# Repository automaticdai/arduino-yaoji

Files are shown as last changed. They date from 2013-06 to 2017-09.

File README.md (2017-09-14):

# Yaoji - An AR Digital Plant on Arduino and Android
妖姬 - 基于Arduino和Android的虚拟电子植物

----------

## 1. About Yaoji
Yaoji is an open-source digital plant based on Arduino and Android. It is based on the popular idea of Augmented Reality (AR). By using the deployed sensors and Leds on Yaoji, users can interact with Yaoji and see its response on an Android phone.

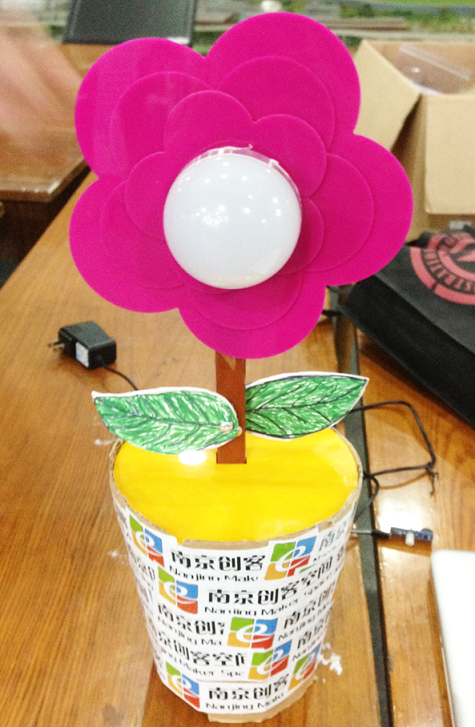
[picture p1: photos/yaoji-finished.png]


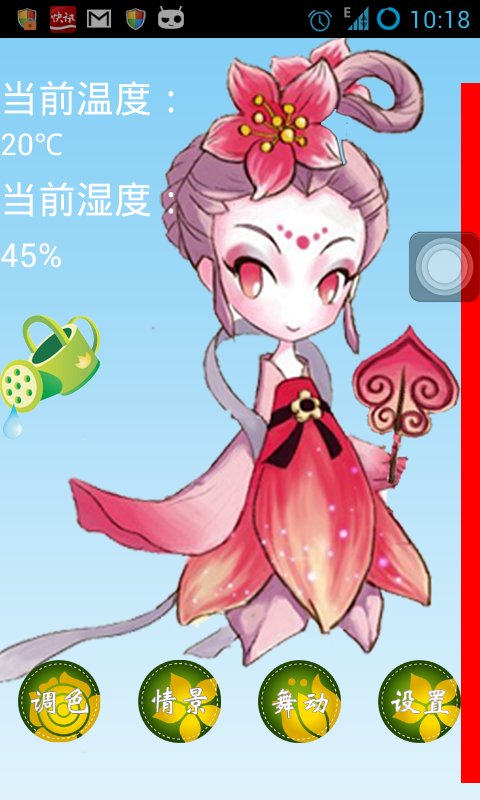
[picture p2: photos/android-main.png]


Yaoji has five full-RGB leds, one illumination sensor, one temperature & humidity sensor and one infrared sensor. Yaoji uses an Arduino Nano 3.0 as the core controller and a wifi module as a bridge to communicate with the Android app. It was a prize-winning (third prize) project in Geekon Hackmarthon in 2013.

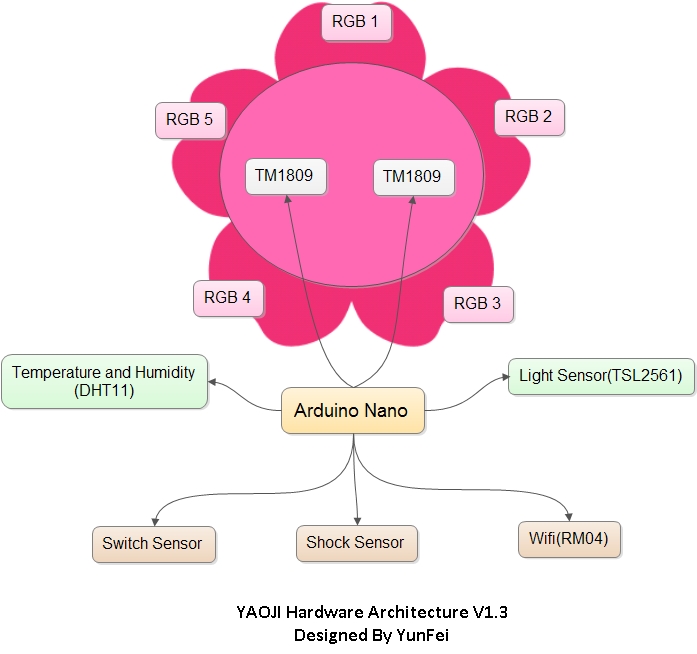
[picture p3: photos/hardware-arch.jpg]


## 2. Project Directory
### /documents
descriptions, datasheets and communication protocol

### /hardware
schematics, pcb and mechanical CAD

### /photos
photos of Yaoji.

### /software
- **/arduino**: Arduino source code and libraries of the firmware (.ino).

- **/android**: user application on Android (.apk).

- **/windowns**: a Windows demo of a sound analyzer that transfer sound spectrum into LED color (Visual Studio Project).

## 3. Contributors
|Name |Role|
|--- |----|
|YunFei  | System Design & Arduino Programming |
|leepood | Android App Development |
|Congbin Zhong | Hardware Design and Debug |

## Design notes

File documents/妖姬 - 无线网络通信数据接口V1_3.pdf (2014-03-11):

妖 姬

# 无线网络通信数据接口

# 南京创客空间

# Nanjing Maker Space

2013 年 6 月

目 录

# 一、通信概述

妖姬使用 Wifi 与客户端进行无线通信，其自身作为无线 AP 热点，使用 UDP 与客户端进行通 信。妖姬默认为空闲模式，进行数据通信前，客户端首先需要建立连接。建立连接后，妖姬 会切换为通信模式，等待客户端发送数据请求。通信期间，客户端需要以固定间隔发送心跳 请求，若超过一定时间没有接收到心跳请求，妖姬会切换回空闲模式，不再响应客户端的请 求。客户端也可主动发送退出连接请求使妖姬切换为空闲模式，空闲模式下妖姬的动作模式 可由客户端配置。

妖姬的通信参数如下：
网络 SSID：yaoji-wifi
网络密钥：yaoji
通信方式：UDP/IP
IP 地址：192.168.1.1
端口号：10001
通信超时：3s，发送数据后若超过该时间没有接收到响应，则需进行重发。 通信重试次数：3 次，通信超时次数若超过该次数，则认为通信失败。 心跳间隔：30s，由客户端定时发送。
空闲超时：60s，在连接状态下，若超过该时间没有接收到心跳，则退出通信模式。

数据类型定义：
数据使用网络字节序大端模式，数据类型如下：
BYTE | 8 位无符号整数，[0-255]
INT16U | 16 位无符号整数，[0-65535]
INT32 | 32 位有符号整形，[-2147483648, +2147483647]
FLOAT | 32 位浮点数类型。
STRING | 字符串类型，需要以’\0’结尾。
BYTE[n] | 长度为 n 的 BYTE 型数组。

# 二、数据帧格式

数据帧符合 UDP/IP 协议，数据定义如下：
开始位(2B) | 数据长度(2B) | 消息类型(2B) | 消息体(nB) | 数据校验(2B) | 结束位(1B)
0x55 0xAA | LENGTH | COMMAND | BODY | BCC | 0x0D

对以上各消息域的说明如下：
LENGTH | 消息总长度 = 消息类型长度 + 消息体长度 + 数据校验长度。每一帧的数 据长度不得超过 1024B。
COMMAND | 消息类型，两字节。
BODY | 消息体：消息类型不同，则长度与内容不同。
BCC | 从”数据长度”至”消息体”之间的所有字节进行累加求和(包括数据长度及消 息体自身)，截取末尾两字节作为校验。

# 三、消息定义

## 3-1 建立连接 CONN

消息类型：0x0001
数据方向：Client -> YAOJI
消息说明：
发送该报文，建立客户端与妖姬的数据连接。
消息定义：
通信协议版本(INT16U 2B) | 保留(INT16U 2B)
V1.12 表示为 0x0112

## 3-2 连接响应 CONN ACK

消息类型：0x8001
数据方向：YAOJI -> Client
消息说明：
对连接请求进行响应。
消息定义：
连接结果(BYTE 1B)
0x00 成功，0x01 已经建立连接，0x02 连接失败(协议版本不一致)

## 3-3 心跳 HRT

消息类型：0x0002
数据方向：Client -> YAOJI
消息说明：
客户端定时发送心跳，维持妖姬的通信状态。若超过空闲时间仍然接收不到心跳，则妖 姬主动断开本次连接。
消息定义：
无消息体。

## 3-4 心跳响应 HRT ACK

消息类型：0x8002
数据方向：YAOJI -> Client
消息说明：

妖姬对心跳进行响应。
消息定义：
心跳结果(BYTE 1B)
0x00 心跳成功，0x01 心跳失败，尚未建立连接

## 3-5 退出连接 DISCON

消息类型：0x0003
数据方向：Client -> YAOJI
消息说明：
客户端主动断开连接。
消息定义：
无消息体。

## 3-6 退出响应 DISCON ACK

消息类型：0x8003
数据方向：YAOJI -> Client
消息说明：
妖姬响应客户端请求，并退出连接。
消息定义：
退出结果(BYTE 1B)
0x00 退出成功，0x01 退出失败，尚未建立连接

## 3-7 读取请求 READ REQUEST

消息类型：0x0004
数据方向：Client -> YAOJI
消息说明：
客户端从妖姬读取参数，包括当前状态、RGB LED 控制值、环境状态等数据。 消息定义：
参数索引(INT16U 2B)
读取参数的索引号，见附录 1。

## 3-8 读取响应 READ ACK

消息类型：0x8004

数据方向：YAOJI-> Client
消息说明：
妖姬响应客户端的读取请求。
消息定义：
参数索引(INT16U 2B) | 参数长度(INT16U 2B) | 参数值(nB)
读取参数的索引号，见附录 1。 | 参数值的字节大小。 0 表示读取失败。 | 参数值域，该长度 n 在参数长 度域给出。该参数的类型解释 是由其参数索引决定的。

## 3-9 写入请求 WRITE REQUEST

消息类型：0x0005
数据方向：Client-> YAOJI
消息说明：
客户端向妖姬写入数据，如修改 LED 的状态、工作模式等。
消息定义：
参数索引(INT16U 2B) | 参数长度(INT16U 2B) | 参数值(nB)
写入参数的索引号，见附录 1。 | 参数值的字节大小。 0 表示读取失败。 | 参数值域，该长度 n 在参数长 度域给出。该参数的类型解释 是由其参数索引决定的。

## 3-10 写入响应 WRITE ACK

消息类型：0x8005
数据方向：YAOJI ->Client
消息说明：
妖姬响应客户端的写入请求。
消息定义：
参数索引(INT16U 2B) | 操作结果(BYTE 1B)
写入参数的索引号，见附录 1。 | 0x00 写入成功 0x01 写入失败(不存在的索引或为只读参数) 0x02 写入失败(超过数据范围)

# 附 1.参数索引表

索引 | 名称 | 类型 | 范围 | R/W | 备注
0x00 | 当前生命 | INT16U | 0-1000 | R/W | [0.1%]当前生命值，浇水可以恢复。
0x01 | 空闲模式 | INT16U | 0-20 | R/W | 设置空闲模式下妖姬的行为模式。
0x02 | 温度 | INT32 | -500-800 | R | [0.1°C]当前环境温度
0x03 | 湿度 | INT32 | 0-1000 | R | [0.1%]环境湿度
0x04 | 气压 | INT32 | 5000-10600 | R | [0.1hPa]当前大气压强度
0x05 | 照度 | INT32 | 0-200000 | R | [1Lux]当前环境光照强度
0x06 | LED1-RGB | BYTE[3] | 0-255 | R/W | LED1 三通道的颜色，顺序为 R-G-B。
0x07 | LED2-RGB | BYTE[3] | 0-255 | R/W | LED2 三通道的颜色，顺序为 R-G-B。
0x08 | LED3-RGB | BYTE[3] | 0-255 | R/W | LED3 三通道的颜色，顺序为 R-G-B。
0x09 | LED4-RGB | BYTE[3] | 0-255 | R/W | LED4 三通道的颜色，顺序为 R-G-B。
0x0A | LED5-RGB | BYTE[3] | 0-255 | R/W | LED5 三通道的颜色，顺序为 R-G-B。
0x0B | LED-ALL | BYTE[3] | 0-255 | W | 同时设置所有的 LED 为该颜色，设 置顺序为 R-G-B。
0x0C | LED-Burst | BYTE[15] | 0-255 | R/W | 批量设置 / 读取所有的 LED 颜色， 设置顺序为： [0-1-2]RGB1 [3-4-5]RGB2 [6-7-8]RGB3 [9-10-11]RGB4 [12-13-14]RGB5
0x0D | SHOCK | BYTE | 0-1 | R/W | 发生震动，写 0 清除。
0x0E | INTERACT_1 | BYTE | 0-1 | R | 交互传感器 1
0x0F | INTERACT_2 | BYTE | 0-1 | R | 交互传感器 2
0x10 | Sensor -Burst | INT16U+ INT32+I NT32+IN T32+BYT E[3] | \ | R | 批量读取 Sensor。顺序：生命、温 度、湿度、光照、震动、交互传感 1、 交互传感 2。
0x11 | Environment | INT8U | 0-2 | R/W | 设置/读取当前的情景模式
0x12
0x13
0x14

空闲模式说明：
0x00 : 空闲模式下关闭所有 LED
0x01 : 保持最后的状态
0x02 : 进入呼吸模式
0x03 : 进入生命模式
0x04 : 进入温度检测模式

0x05 : 进入湿度检测模式

情景模式说明：
0x00：关闭情景模式
0x01：静如流水
0x02：动如脱兔

# 附 2.修订历史

日期 | 版本 | 修订内容 | 修订人
13-06-24 | V1.0 | ·完成通信协议初稿。 | 戴晓天
13-06-25 | V1.1 | ·LED 的颜色以 RGB 为一组同时设置，支持了同时设置所 有 LED 的颜色，提高通信效率。 ·增加了对空闲模式的解释。 | 戴晓天
13-06-29 | V1.2 | ·增加了 16 位无符号整形数据结构 INT16U ·将 ARRAY[n]型数据更名为 BYTE[n] ·将 INT 数据类型更名为 INT32 ·将参数标签和参数长度域修改为 16 位，提高通信效率 ·修改了排版与部分文字说明，增加了目录 ·修改了部分参数的数据类型 | 戴晓天
13-07-07 | V1.3 | ·增加了读取震动传感器、交互传感器，以及传感器批 量读取命令。 ·增加了情景模式设置 | 戴晓天

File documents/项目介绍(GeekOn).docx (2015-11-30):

妖姬项目介绍 - Geekon

● 什么是妖姬

妖姬是互联网时代的宠儿，是一种兼容办公室与居家生活的桌面电子植物。她不仅仅是一展能变换万千色彩的LED灯，她也像真实的植物一样具有情感与生命，她是夜色下妩媚的女神，也是你生活不可缺少的助手。

妖姬基于开源硬件Arduino，五片全彩LED是她的霓裳，可以通过iphone手机控制她的颜色，什么颜色由你定！妖姬使用内置锂电池供电，通过无污染绿色的太阳能进行充电，同时可以用5V USB对她放电，千万别用太高的电压，会电晕她的。

● 和她约会

孤枕难眠：可化作一朵白色雪莲，做你的书童陪你挑灯夜战，做小夜灯帮你吸引蚊子。

激情四射：多种颜色变换，炫舞效果，不同的颜色，按照设定好的节奏闪动。

静如流水：她在夜晚尽展其温柔一面，通过柔和的灯光变换，让你感受从未有过的宁静。

舞动音乐：妖姬随着音乐的旋律，变为月夜下的舞娘。

● 呵护妖姬

妖姬具有独特的生命系统，要像呵护女朋友一样呵护她，您的悉心呵护才能让她茁壮成长，她能通过自身的颜色变化呈现目前的生命状态。开心时心花怒放，不开心时候怒火冲天。当你看到她显示红色的时候，说明她生气了，在发火呢 (赶紧去哄哄她)。如果看上去情况不妙，那就该打开app给她浇水了！

● 妖姬天气

妖姬不止是一个风华绝代的玩物，她还是您的私人气象站。妖姬具有多种环境传感器，只要打开手机APP，就能看见家中温度、湿度、气压、照度情况，真是太赞了！

● 妖姬的由来 (野史)

历世真仙体道通鉴，曾经提起西王母有女儿，有名可查者有六位： 一、四女名为华林，字容真，号紫元夫人，南极元君或称南极王夫人； 二、第十三女名为媚兰，字申林，号右英王夫人，云林夫人或称沧浪云林右英夫人； 三、第二十女名叫清娥，字愈音，或愈意，号紫微王夫人； 四、第二十三女，名为瑶姬，号曰云华夫人； 五、么女，名婉罗或者玉卮，字勃遂，号曰太真王夫人； 六、妖姬，号曰七彩妖姬。

西王母育女多人，有事女儿代其效劳，书中所说王母乃天帝之女，而天帝在道藏记载，分有青、黄、白、黑四天帝，王母到底所指是哪一位天帝，到今日也无 人知晓，西王母仙居在何处，至今也是众人所迷惑，吏书虽有记载但未成定论。

西王母最疼爱的小女儿：妖姬，天资聪颖，天生丽质，古灵精怪，常在天庭里捣乱。妖姬经常跑太上老君和其他众神家去捣蛋，搞破坏。玉皇大帝接受到很多 投诉电话，非常烦恼，想早点把她嫁出去，于是跟王母商量准备把妖姬许配给二郎神。妖姬听说此事后非常生气，想自己的婚姻自己做主。得知民间有非诚勿 扰，随即报名参加了江苏电视台的非诚勿扰。

一枚挨踢吊死男，上了非诚勿扰，看中了天生丽质的妖姬。此时妖姬也被该挨踢男的痴情打动，牵手成功。幸福来的太突然，正当他们还沉浸在幸福中，哪知 那天有不测风云，此时天庭知道妖姬私自下凡人间，派托塔李天王前来捉拿妖姬。妖姬宁死不屈，化作一朵七色彩花。挨踢男伤心欲绝，化作花叶花茎一直陪伴妖姬身边。

虽然目前这个设计还停留在空想阶段，不过我们会发挥极客精神，把想法变成现实。希望大家支持我们，支持南京创客空间，我们“极客行动”见！

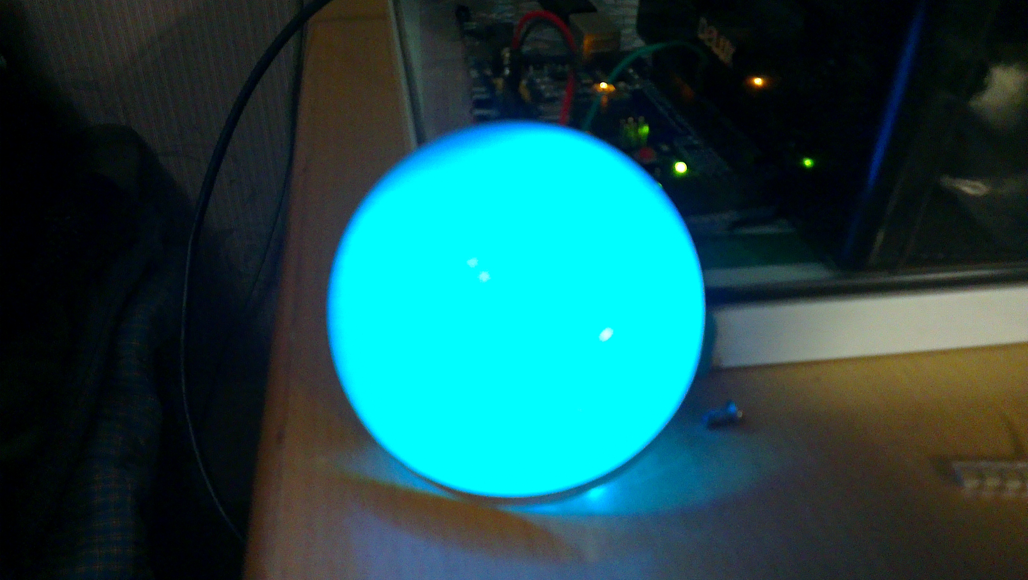
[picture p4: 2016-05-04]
photos/RGB调色3.jpg

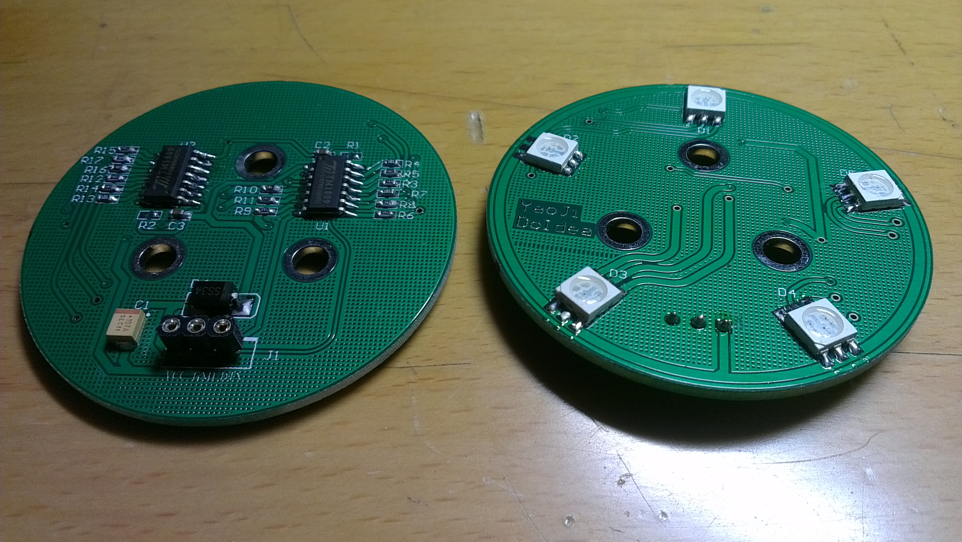
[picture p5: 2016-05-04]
photos/硬件（花盘）.jpg

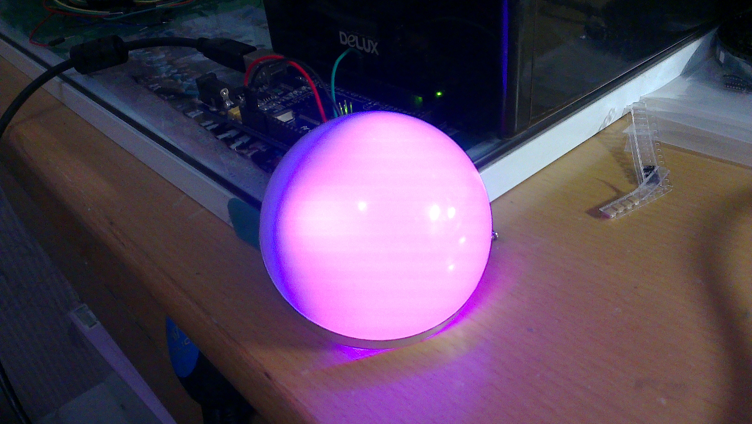
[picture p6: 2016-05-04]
photos/RGB调色1.jpg

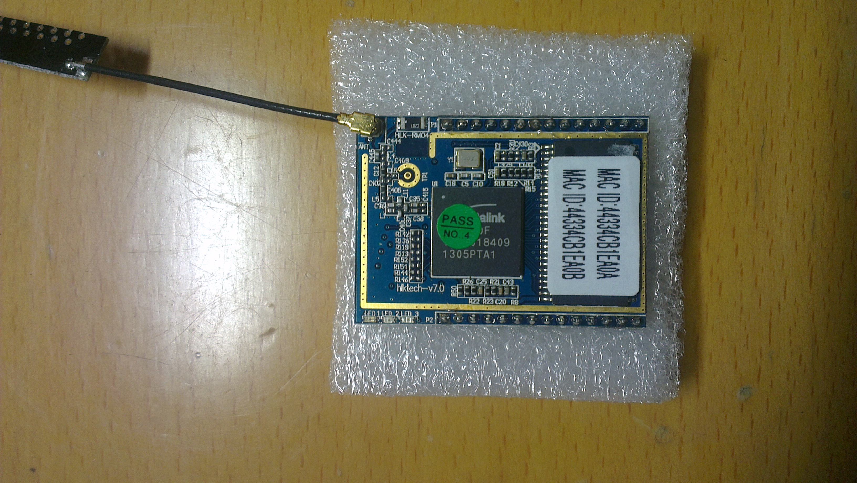
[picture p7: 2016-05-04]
photos/WiFi模块.jpg

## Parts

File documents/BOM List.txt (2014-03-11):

Arduino Nano 	* 1	50.0
5050 RGB LED 	* 6	0.5 * 6 = 3.0
TM1809 		* 2	1.0 * 2 = 2.0
Solar Battery 	* 1	55
5V DC Adaptor 	* 1	10
DHT11 		* 1	15
BMP085 		* 1	8.5
TSL2561 	* 1	15.0
RM04 UartToWifi * 1	68.0
PCB		* 2	5.0 * 2 = 10.0

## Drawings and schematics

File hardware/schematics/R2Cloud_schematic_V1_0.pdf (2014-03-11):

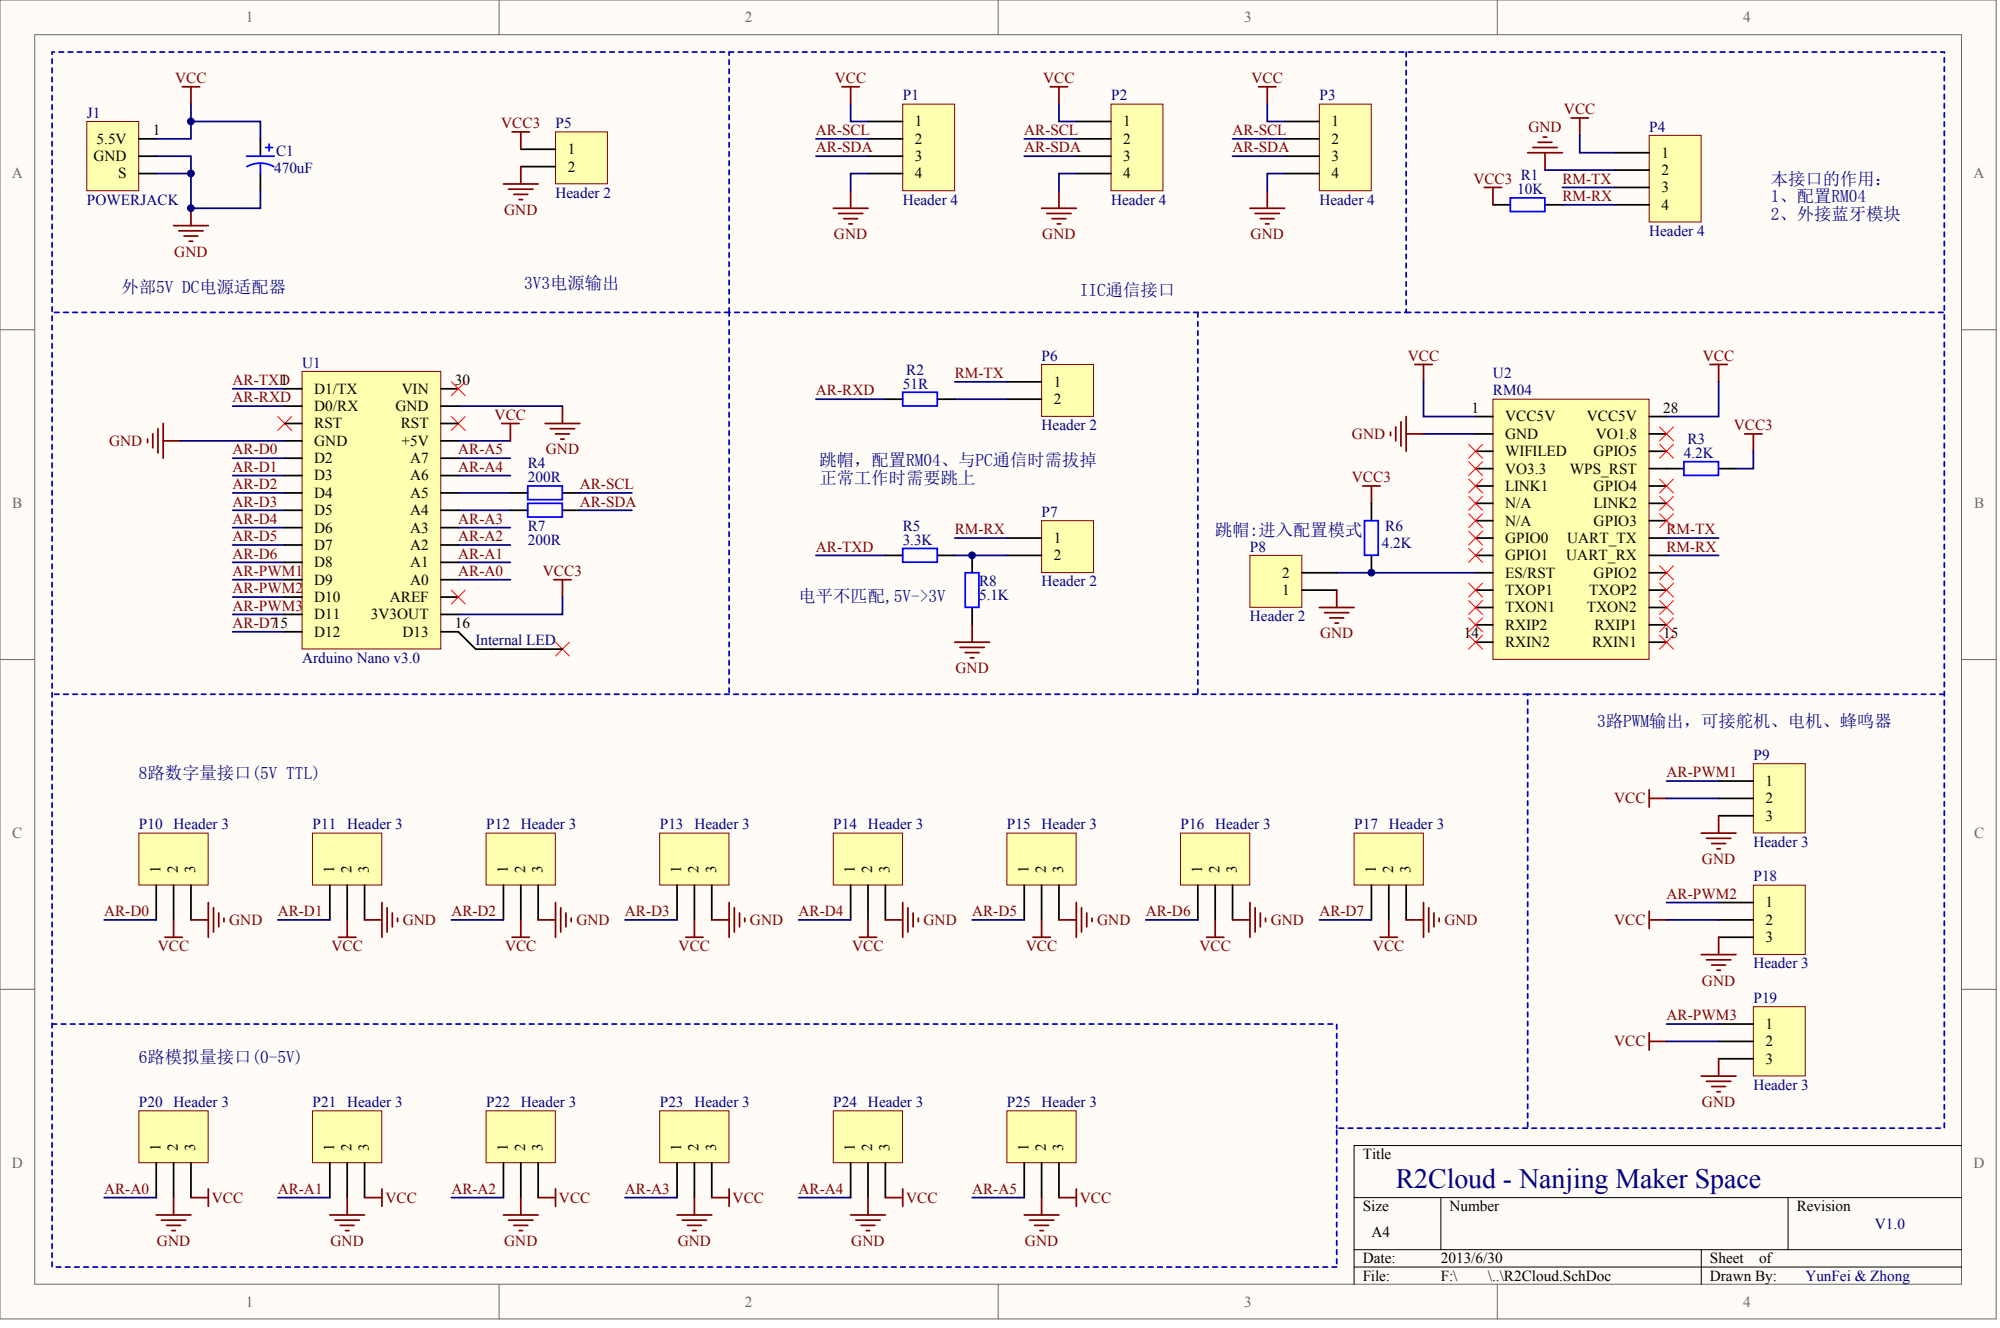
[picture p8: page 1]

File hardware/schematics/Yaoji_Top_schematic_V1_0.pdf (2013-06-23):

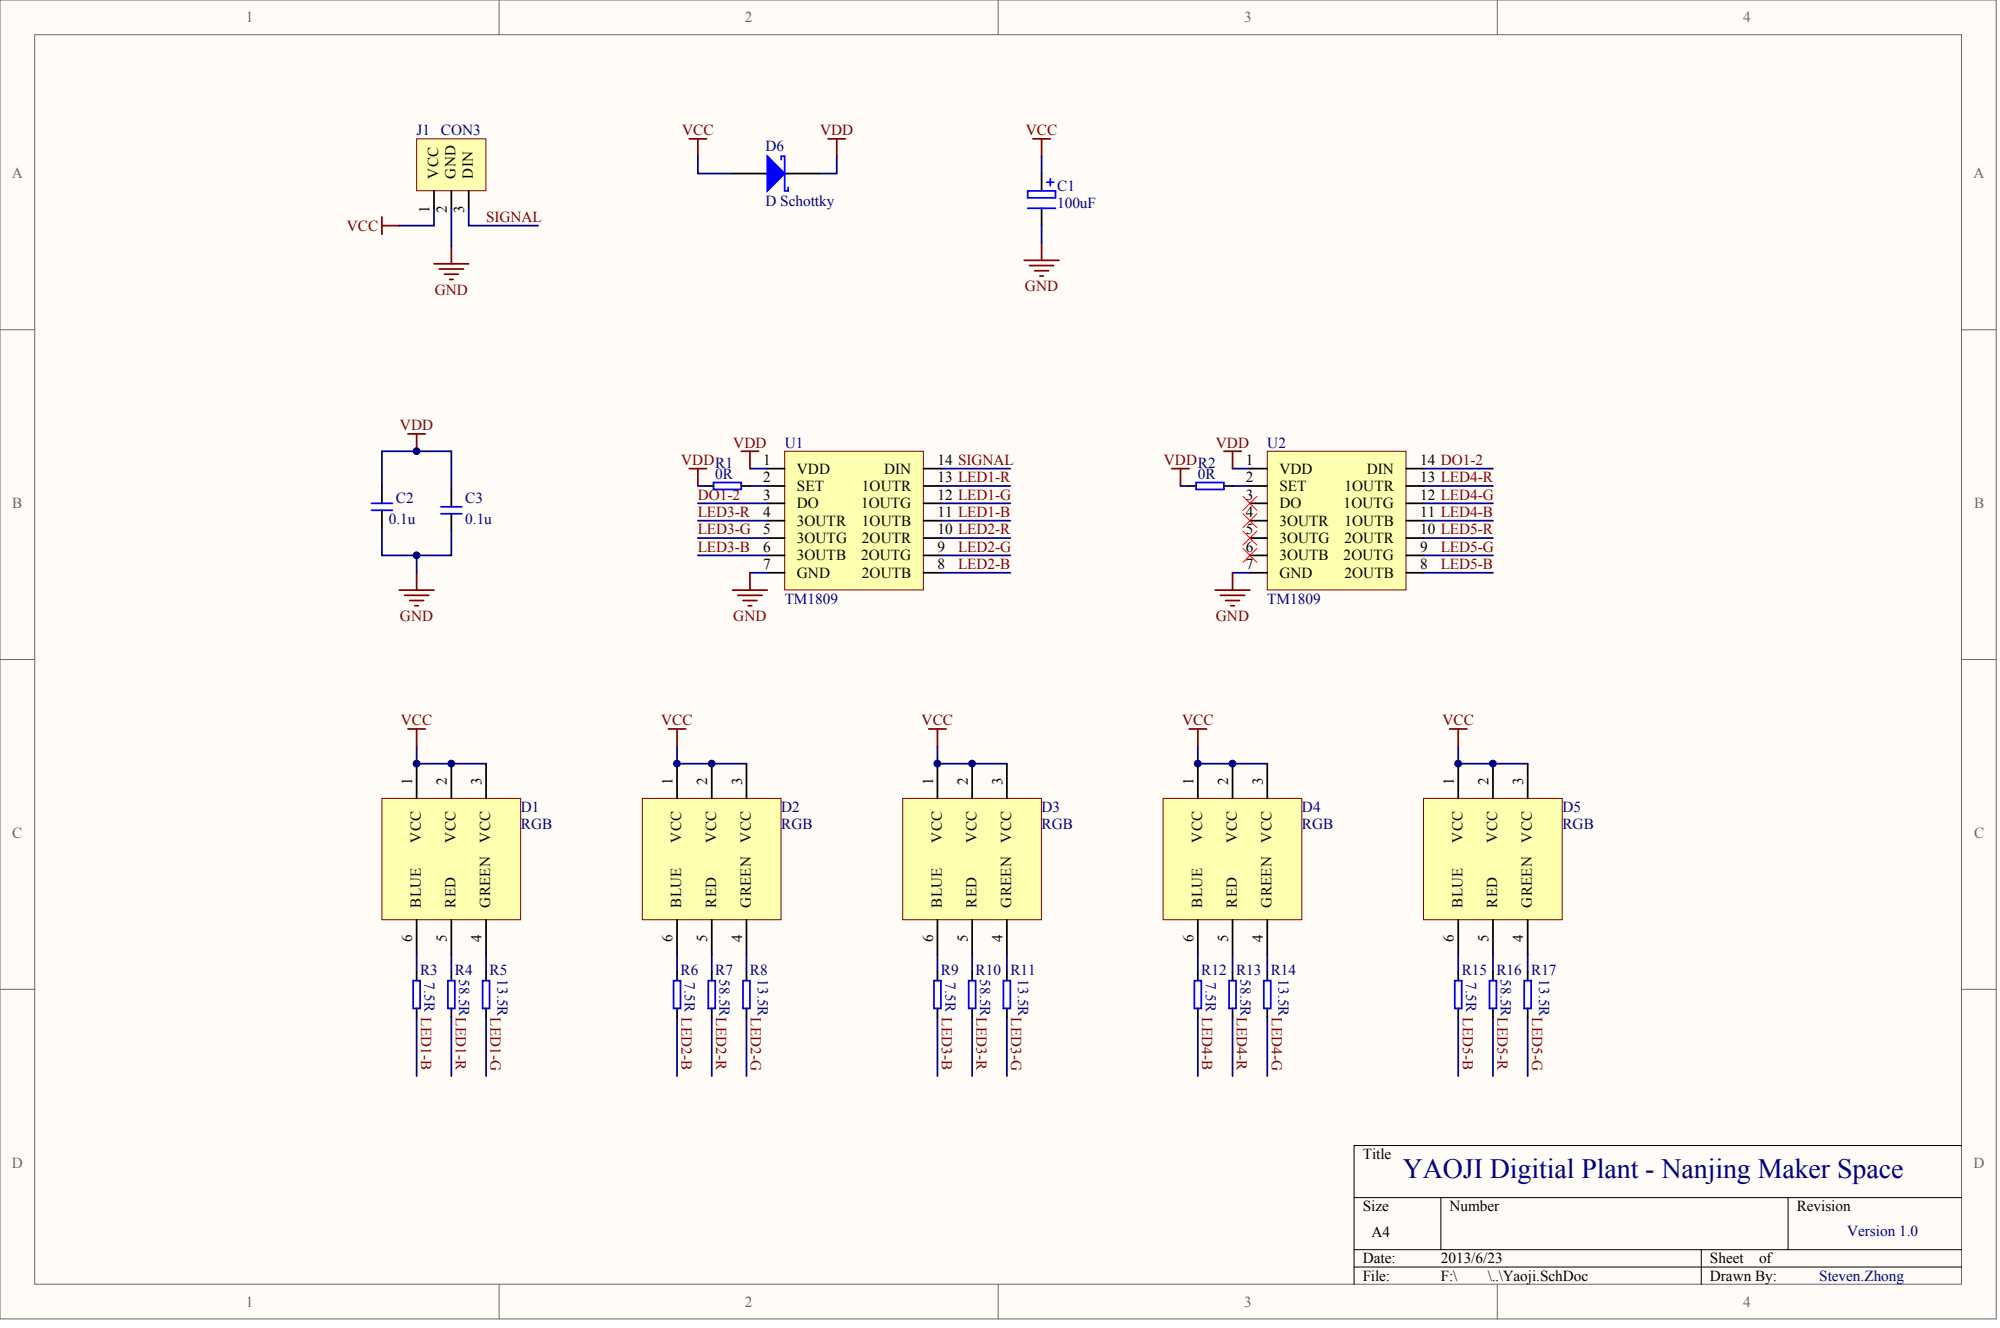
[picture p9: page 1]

Title
YAOJI Digitial Plant - Nanjing Maker Space

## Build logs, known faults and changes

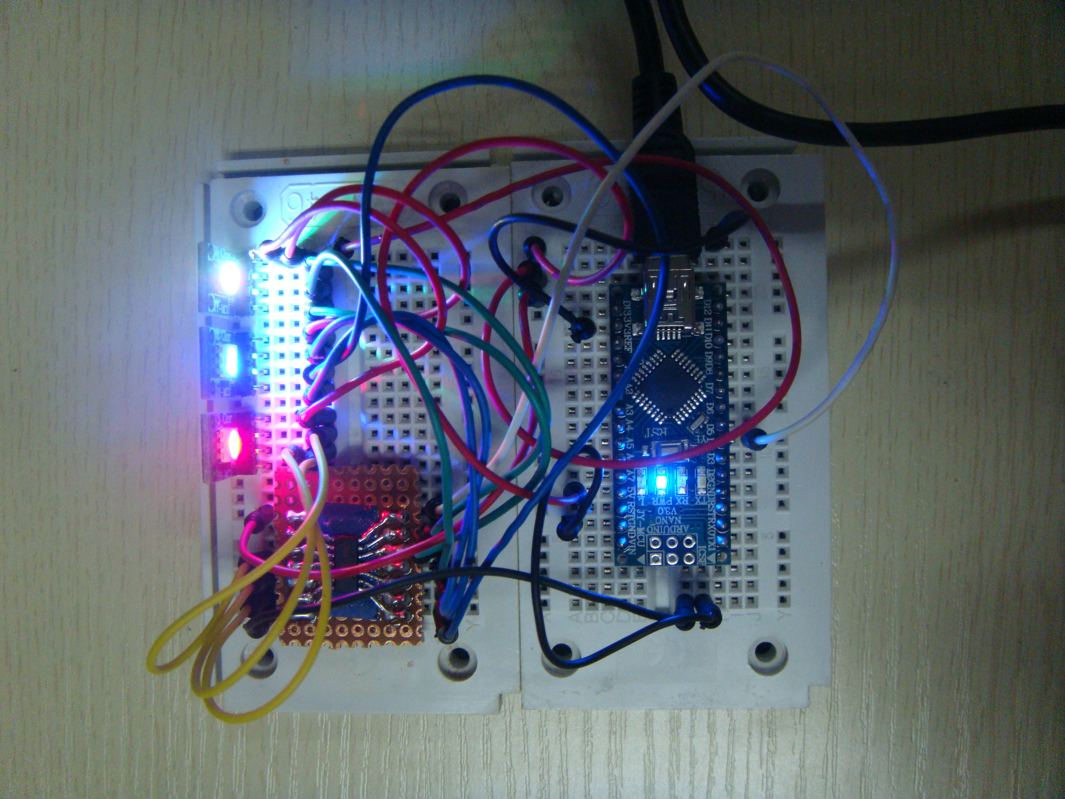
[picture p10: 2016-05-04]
photos/调试电路.JPG

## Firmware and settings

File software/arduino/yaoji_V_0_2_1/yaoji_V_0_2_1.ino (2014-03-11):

  /*-----------------------------------------------------------------------------
 Project      : YAOJI Digital LED Plant
 Author       : YunFei
 E-mail       : automatic.dai@gmail.com
 Website      : http://www.yfworld.com
 Version      : V0.1.0
 Last_Updated : 06/30/2013
-----------------------------------------------------------------------------*/

#include <timer.h>
#include <FastSPI_LED2.h>
#include <dht.h>
#include <Wire.h>

///////////////////////////////////////////////////////////////////////////////
// R2Clound Pin Assign
#define	ARD0	(2)
#define ARD1	(3)
#define ARD2	(4)
#define ARD3	(5)
#define ARD4	(6)
#define ARD5	(7)
#define ARD6	(8)
#define ARD7	(12)

#define ARA0	(0)
#define ARA1	(1)
#define ARA2	(2)
#define ARA3	(3)
#define ARA4	(6)
#define ARA5	(7)

#define ARPWM1	(9)
#define ARPWM2	(10)
#define ARPWM3	(11)

#define	ARLED	(13)
///////////////////////////////////////////////////////////////////////////////
dht 	DHT;
CTimer	tm_action;
CTimer	tm_sensor;
CTimer	tm_life;
///////////////////////////////////////////////////////////////////////////////
// CYaoji
#define YAOJI_STATE_IDLE		(0x00)
#define YAOJI_STATE_BUSY		(0x01)

// PINs Defination
#define TM1809_PIN				(ARD2)		// put the tm1809 signal in D4
#define DHT11_PIN               (ARD4)		// put the dht sensor in D6
#define SHOCK_PIN				(ARD5)
#define INTERACT_PIN			(ARD6)

// Macro Defination
#define YAOJI_DEBUG_ON			(0)
#define YAOJI_LED_NUMBERS 		(5)

#define PARAM_LIFE				(0x0000)
#define PARAM_IDLE_MODE			(0x0001)
#define PARAM_TEMPERATURE		(0x0002)
#define PARAM_HUMIDITY			(0x0003)
#define PARAM_PRESSURE			(0x0004)
#define PARAM_LUMIN				(0x0005)
#define PARAM_RGB1				(0x0006)
#define PARAM_RGB2				(0x0007)
#define PARAM_RGB3				(0x0008)
#define PARAM_RGB4				(0x0009)
#define PARAM_RGB5				(0x000A)
#define PARAM_RGBALL			(0x000B)
#define PARAM_RGBBURST			(0x000C)
#define PARAM_SENSOR_BURST		(0x0010)
#define PARAM_ENVIRONMENT		(0x0011)

class CYaoji
{
 // Members
 private:
	int 	state;					// 0x00 IDLE, 0x01 BUSY
	int 	idle_mode;				// 0 - 20
	int		busy_mode;				// Environment situation with BUSY
	byte	lamp_current_state;		// If lamp is on or off when in IDLE
	int 	life;					// 0 - 1,000 * 0.1%
 	int 	temperature;			// -500 - 800
	int 	humidity;				// 0 - 1,000
	long 	pressure;				// 5,000 - 106,000
    long	lux;					// 0 - 200,000
	int		shock;					// 
	int		infra1;					//
	int		infra2;					//
	int		breathe;				//
	
 public:
	struct CRGB rgbleds[YAOJI_LED_NUMBERS];			// RGB LED Array
	struct CRGB rgbleds_last[YAOJI_LED_NUMBERS];	// RGB LED Array(Last)
 // Functions
 private:
	
 public:
	CYaoji();
	~CYaoji();
	
	void 	init(void);
	void	updateSensors(void);
	void	commWithClient(void);
	void	interactFromEnv(void);
	void	decisionMake(void);
	void	takeAction(void);
    void    refreshRGB(void);
	void	selfCheck(void);
};

CYaoji::CYaoji()
{
	state = 0x00;
	idle_mode = 0x00;
	life = 1000;
	temperature = 0;
	humidity = 0;
	pressure = 0;
	lux = 0;
	memset(rgbleds, 0, YAOJI_LED_NUMBERS * sizeof(struct CRGB));
	lamp_current_state = 0;
	tm_action.setTime(100);
	tm_sensor.setTime(1000);
	tm_life.setTime(50);
}

CYaoji::~CYaoji()
{
	;
}

void CYaoji::init(void)
{
	// read config form eeprom;
	// init Serial
	serialInit(9600);
	
	// init iic
	Wire.begin();
	
	// init DHT11
	int chk = DHT.read11(DHT11_PIN);
#if (YAOJI_DEBUG_ON)
	switch (chk)
	{
		case -1: Serial.print("DHT>>Checksum error,\t"); break;
		case -2: Serial.print("DHT>>Time out error,\t"); break;
		default: Serial.print("DHT>>Unknown error,\t"); break;
	}
#endif

	// init BMP085
	// bmp085Calibration();
  
	// init BH1750
	
	// init TM1809 and LEDs
   	LEDS.setBrightness(100);
   	LEDS.addLeds<TM1809, TM1809_PIN>(rgbleds, YAOJI_LED_NUMBERS);
	memset(rgbleds, 0, YAOJI_LED_NUMBERS * sizeof(struct CRGB));
	LEDS.show();

	// init interact sensor
	pinMode(SHOCK_PIN, INPUT);
	pinMode(INTERACT_PIN, INPUT);
	
	// init system led
	pinMode(ARLED, OUTPUT);
	
}

void CYaoji::updateSensors(void)
{
	if ( tm_sensor.getReached() )
	{
		tm_sensor.resetTime();
      	// Read DHT11
      	if ( DHT.read11(DHT11_PIN) == 0 )
      	{
      		humidity = DHT.humidity * 10;
      		temperature = DHT.temperature * 10;
      	}
      	
      	// Read BMP085
      	//temperature = bmp085GetTemperature(bmp085ReadUT());
      	//pressure = bmp085GetPressure(bmp085ReadUP());
      	
      	// Sample BH1750
      	lux = BH1750_GetLux();
#if (YAOJI_DEBUG_ON)
		Serial.println(temperature);
		Serial.println(humidity);
		Serial.println(lux);
		Serial.println();
#endif
}
	
}

#define COMM_CMD_CONN			(0x0001)
#define COMM_CMD_CONNACK		(0x8001)
#define COMM_CMD_HRT			(0x0002)
#define COMM_CMD_HRTACK			(0x8002)
#define COMM_CMD_DISCON			(0x0003)
#define COMM_CMD_DISCONACK		(0x8003)
#define COMM_CMD_READREQUEST	(0x0004)
#define COMM_CMD_READACK		(0x8004)
#define COMM_CMD_WRITEREQUEST	(0x0005)
#define COMM_CMD_WRITEACK		(0x8005)

void CYaoji::commWithClient(void)
{

	serialHandle();				// get data from serial port
		
	if ( serialGetReady() )
	{
		byte *pbuff = serialGetBuff();
		int cmdLength = serialGetLength();
                
		// ack
		byte pack_ack_buff[50];
		byte *pack_ack = pack_ack_buff;

		// Param TLV
		long tag;
		long length;
		long value;
                
		// frame check
		int commandID = *(pbuff) << 8 | *(pbuff+1);
		int verifyWord = *(pbuff+cmdLength-2) << 8 | *(pbuff+cmdLength-1);
		pbuff += 2;
		cmdLength -= 4;
		
		state = YAOJI_STATE_BUSY;
		// Blink a led
		if ( digitalRead(ARLED) == HIGH )
		{
			digitalWrite(ARLED, LOW);
		}
		else
		{
			digitalWrite(ARLED, HIGH);
		}
		
		// frame analysis
		switch ( commandID )
		{
			case COMM_CMD_CONN:
			#if (YAOJI_DEBUG_ON)
				Serial.println("Client>>Conn Cmd");
			#endif			
				break;
				
			case COMM_CMD_HRT:
			#if (YAOJI_DEBUG_ON)
				Serial.println("Client>>HRT Cmd");
			#endif
				break;
				
			case COMM_CMD_DISCON:
			#if (YAOJI_DEBUG_ON)
				Serial.println("Client>>Disconn Cmd");
			#endif
				break;
				
			case COMM_CMD_READREQUEST:
			#if (YAOJI_DEBUG_ON)
				Serial.println("Client>>Read Request");
			#endif
				// TAG
				tag = *pbuff++;
				tag = tag << 8 | *pbuff++;
						
				// VALUE
				switch (tag)
				{
					// INT TYPE
					case PARAM_LIFE:
						break;
					case PARAM_IDLE_MODE:
						break;
					case PARAM_TEMPERATURE:
						break;
					case PARAM_HUMIDITY:
						break;
					case PARAM_PRESSURE:
						break;
					case PARAM_LUMIN:
						break;
					
					// BYTE TYPE
					case PARAM_RGB1:
						break;
					case PARAM_RGB2:
						break;
					case PARAM_RGB3:
						break;		
					case PARAM_RGB4:
						break;			
					case PARAM_RGB5:
						break;		
					case PARAM_RGBBURST:
						break;
					
					// Other
					case PARAM_SENSOR_BURST:
						// life
						*pack_ack++ = (byte)(life>>8); 
						*pack_ack++ = (byte)life;			
						// temperature 
						*pack_ack++ = (byte)(temperature>>8); 
						*pack_ack++ = (byte)temperature;												
						// shock(clear after read)
						*pack_ack++ = shock;
						shock = 0;
						serialSendPackage(COMM_CMD_READREQUEST, pack_ack_buff, 5);
						break;
					
					case PARAM_ENVIRONMENT:
						break;
						
					default:
						;
				}				
				break;
				
			case COMM_CMD_WRITEREQUEST:
			#if (YAOJI_DEBUG_ON)
				Serial.println("Client>>Write Request");
			#endif
				// TAG
				tag = *pbuff++;
				tag = tag << 8 | *pbuff++;
				
				// LENGTH
				length = *pbuff++;
				length = length << 8 | *pbuff++;
				
				// VALUE
				switch (tag)
				{
					// INT TYPE
					case PARAM_LIFE: 
						value = *pbuff++;
						value = value << 8 | *pbuff++;
						break;
						
					case PARAM_IDLE_MODE:
						value = *pbuff++;
						value = value << 8 | *pbuff++;
						break;
						
					// BYTE TYPE
					case PARAM_RGB1: rgbleds[0] = CRGB(*pbuff, *(pbuff+1), *(pbuff+2)); busy_mode = 0x00; break;
					case PARAM_RGB2: rgbleds[1] = CRGB(*pbuff, *(pbuff+1), *(pbuff+2)); busy_mode = 0x00; break;
					case PARAM_RGB3: rgbleds[2] = CRGB(*pbuff, *(pbuff+1), *(pbuff+2)); busy_mode = 0x00; break;	
					case PARAM_RGB4: rgbleds[3] = CRGB(*pbuff, *(pbuff+1), *(pbuff+2)); busy_mode = 0x00; break;			
					case PARAM_RGB5: rgbleds[4] = CRGB(*pbuff, *(pbuff+1), *(pbuff+2)); busy_mode = 0x00; break;	
					
					case PARAM_RGBALL:
						rgbleds[0] = CRGB(*pbuff, *(pbuff+1), *(pbuff+2)); 
						rgbleds[1] = CRGB(*pbuff, *(pbuff+1), *(pbuff+2)); 
						rgbleds[2] = CRGB(*pbuff, *(pbuff+1), *(pbuff+2)); 
						rgbleds[3] = CRGB(*pbuff, *(pbuff+1), *(pbuff+2)); 			
						rgbleds[4] = CRGB(*pbuff, *(pbuff+1), *(pbuff+2));
						busy_mode = 0x00;		// clear environment mode when user set color
						break;		
						
					case PARAM_RGBBURST:
						rgbleds[0] = CRGB(*(pbuff+0), *(pbuff+1), *(pbuff+2)); 
						rgbleds[1] = CRGB(*(pbuff+3), *(pbuff+4), *(pbuff+5));
						rgbleds[2] = CRGB(*(pbuff+6), *(pbuff+7), *(pbuff+8));
						rgbleds[3] = CRGB(*(pbuff+9), *(pbuff+10), *(pbuff+11));	
						rgbleds[4] = CRGB(*(pbuff+12), *(pbuff+13), *(pbuff+14));
						busy_mode = 0x00;		// clear environment mode when user set color
						break;
						
					case PARAM_ENVIRONMENT:
						busy_mode = *pbuff;
					#if (YAOJI_DEBUG_ON)
						Serial.print("Environment Mode :");
						Serial.println(busy_mode);
					#endif
						break;
						
					default:
						;
				}
				break;
			
			default:
				break;
		
		}
		
		// Clear ready
		serialClrReady();
	}
	
}

void CYaoji::interactFromEnv(void)
{
	// Change Yaoji's life
	if ( tm_life.getReached() )
	{
		tm_life.resetTime();
		
		if ( lux < 1000 )
		{
			if ( life != 0 )
			{
				life--;
			}
		}
		else
		{
			if ( life <= 1000 - 10 )
			{
				life += 10;
			}
		}
	}
	
	// Read Sensor
	if ( digitalRead(SHOCK_PIN) == HIGH )
	{
		shock = 0x01;
	}
	
	if ( digitalRead(INTERACT_PIN) == HIGH )
	{
		infra1 = 0x01;
	}
	else
	{
		infra1 = 0x00;
	}

}

int infra_filter;
void CYaoji::decisionMake(void)
{

    CRGB t_rgb;
	
	// Turn on or off LED on IDLE
	if ( state == YAOJI_STATE_IDLE )
	{
		if ( infra1 == 0x01 )
		{
			if ( infra_filter < 10 )
			{
				if ( ++infra_filter >= 10 )
				{
					// Off->On
					if ( lamp_current_state == 0x00 )
					{
						t_rgb = CRGB(200,200,200);
						lamp_current_state = 0x01;
						rgbleds[0] = t_rgb;
						rgbleds[1] = t_rgb;
						rgbleds[2] = t_rgb;
						rgbleds[3] = t_rgb;
						rgbleds[4] = t_rgb;
					}
					// On->Off
					else
					{
						t_rgb = CRGB(0,0,0);
						lamp_current_state = 0x00;
						rgbleds[0] = t_rgb;
						rgbleds[1] = t_rgb;
						rgbleds[2] = t_rgb;
						rgbleds[3] = t_rgb;
						rgbleds[4] = t_rgb;
					}
				}
			}
			

		}
		else
		{
			infra_filter = 0;
		}
	}
	// Environment mode when on BUSY
	else
	{
		if ( busy_mode == 0x01 )
		{
			if ( tm_action.getReached() )
			{
				tm_action.resetTime();
				if ( breathe >= 5 )
				{
					breathe -= 5;
				}
				else
				{
					breathe = 255;
				}
				memset(rgbleds, 0, YAOJI_LED_NUMBERS * sizeof(struct CRGB));
				hsv_to_rgb(breathe, 200, 200, &t_rgb);
				rgbleds[0] = t_rgb;	
				rgbleds[1] = t_rgb;
				rgbleds[2] = t_rgb;
				rgbleds[3] = t_rgb;
				rgbleds[4] = t_rgb;			
			}
		}
		else if ( busy_mode == 0x02 )
		{
			if ( tm_action.getReached() )
			{
				tm_action.resetTime();
				memset(rgbleds, 0, YAOJI_LED_NUMBERS * sizeof(struct CRGB));
				t_rgb = CRGB(random(255),random(255),random(255));
				rgbleds[0] = t_rgb;	
				rgbleds[1] = t_rgb;
				rgbleds[2] = t_rgb;
				rgbleds[3] = t_rgb;
				rgbleds[4] = t_rgb;	
			}				
		}
	}



}

void CYaoji::takeAction(void)
{
	;
}

void CYaoji::refreshRGB(void)
{
	int i;
	boolean led_changed = false;
	
	for ( i = 0; i < YAOJI_LED_NUMBERS; i++ )
	{
		if ( rgbleds_last[i] != rgbleds[i] )
		{
			// need refresh leds
			led_changed = true;
			
			// update last value
			for ( i = 0; i < YAOJI_LED_NUMBERS; i++ )
			{
				rgbleds_last[i] = rgbleds[i];
			}
			break;
		}
	}
	
	if ( led_changed )
	{
		LEDS.show();
	}
}

void CYaoji::selfCheck(void)
{
	// reset watch dog
	// LED Blink
}


///////////////////////////////////////////////////////////////////////////////
// Serial Communication
enum
{
	SERIAL_RX_IDLE      = 0,		// is idle state now, change to 
									// YAOJI_RX_STATE if get 0x55
	SERIAL_RX_START     = 1,		// wait for 0xaa
	SERIAL_RX_LENGTH_H  = 2,		// receive frame length
	SERIAL_RX_LENGTH_L  = 3,
	SERIAL_RX_BODY      = 4,		// receive command id and command body
	SERIAL_RX_WAITEND   = 5,		// wait for 0x0d
}serial_rx_state;

boolean	serial_data_ready;			// false : no frame got, true : got an available frame
int		serial_rx_cnt;
int		serial_rx_len;
int		serial_rx_buff_index;
byte	serial_rx_buff[200];

void serialInit(int baudrate)
{
	serial_data_ready = false;
	serial_rx_cnt = 0x00;
	serial_rx_state = SERIAL_RX_IDLE;
	Serial.begin(baudrate);
}

void serialHandle(void)
{
	byte byte_in;
	
	if (Serial.available() > 0)
	{
		byte_in = Serial.read();
	}
	else
	{
		return;
	}
	
	switch ( serial_rx_state )
	{
		case SERIAL_RX_IDLE:
			if ( byte_in == 0x55 )
			{
				serial_rx_state = SERIAL_RX_START;
			}
			break;
		
		case SERIAL_RX_START:
			if ( byte_in == 0xAA )
			{
				serial_rx_len = 0;
				serial_rx_state = SERIAL_RX_LENGTH_H;
			}
			else
			{
				serial_rx_state = SERIAL_RX_IDLE;
			}
			break;
		
		case SERIAL_RX_LENGTH_H:
			serial_rx_len |= byte_in;
			serial_rx_len <<= 8;
			serial_rx_state = SERIAL_RX_LENGTH_L;
			break;
			
		case SERIAL_RX_LENGTH_L:
			serial_rx_len |= byte_in;
			serial_rx_cnt = serial_rx_len;
			serial_rx_buff_index = 0;
			serial_rx_state = SERIAL_RX_BODY;
			break;
			
		case SERIAL_RX_BODY:
			serial_rx_buff[serial_rx_buff_index] = byte_in;
			serial_rx_buff_index++;
			if ( --serial_rx_cnt == 0 )
			{
				serial_rx_state = SERIAL_RX_WAITEND;
			}
			break;
			
		case SERIAL_RX_WAITEND:
			if (byte_in == 0x0D)
			{
				serial_data_ready = true;
			}
			else
			{
				serial_rx_state = SERIAL_RX_IDLE;
			}
			break;
			
		default:
			serial_rx_state = SERIAL_RX_IDLE;
	}
}

byte *serialGetBuff(void)
{
	return serial_rx_buff;
}

char serialGetLength(void)
{
	return serial_rx_len;
}

int serialGetReady(void)
{
	return serial_data_ready;
}

void serialClrReady(void)
{
	noInterrupts();
	serial_data_ready = false;
	serial_rx_state = SERIAL_RX_IDLE;
	serial_rx_cnt = 0;
	interrupts();
}

void serialSendPackage(short cmdid, byte *cmdbody, int cmdlen)
{
	byte buff[100];
	byte *pbuff = buff;
	int  cmd_len_all;
	
	cmd_len_all = 2 + 2 + 2 + cmdlen + 3;
	
	*pbuff++ = 0x55;
	*pbuff++ = 0xAA;

	*pbuff++ = (byte)((cmd_len_all-5) >> 8);
	*pbuff++ = (byte)(cmd_len_all-5);
	
	*pbuff++ = (byte)((cmdid | 0x8000) >> 8);
	*pbuff++ = (byte)cmdid;
	
	for ( int i = 0; i < cmdlen; i++ )
	{
		*pbuff++ = *cmdbody++;	
	}
	
	*pbuff++ = 0x00;
	*pbuff++ = 0x00;
	*pbuff++ = 0x0D;
	
	Serial.write(buff, cmd_len_all);

}
///////////////////////////////////////////////////////////////////////////////
void hsv_to_rgb (unsigned char h, unsigned char s, unsigned char v, CRGB * out)
{
	unsigned char r=0,g=0,b=0, i, f;
	unsigned int p, q, t;

	if( s == 0 ) {	
		r = g = b = v;
	}
	else
	{	i = h / 43;
		f = h % 43;
		p = (v * (255 - s))/256;
		q = (v * ((10710 - (s * f))/42))/256;
		t = (v * ((10710 - (s * (42 - f)))/42))/256;

		switch( i )
		{	
			case 0:
				r = v; g = t; b = p; break;
			case 1:
				r = q; g = v; b = p; break;
			case 2:
				r = p; g = v; b = t; break;
			case 3:
				r = p; g = q; b = v; break;			
			case 4:
				r = t; g = p; b = v; break;				
			case 5:
	 			r = v; g = p; b = q; break;
		}
	}
	out->r=r; out->g=g; out->b=b;
}

///////////////////////////////////////////////////////////////////////////////
int BH1750ADDR = 0x23;
byte bh_buff[2];
double BH1750_GetLux()
{
	 int i = 0;
	 double val = 0;

	 Wire.beginTransmission(BH1750ADDR);
	 Wire.write(0x10);
	 Wire.endTransmission();
	 delay(20);

	 Wire.beginTransmission(BH1750ADDR);
	 Wire.requestFrom(BH1750ADDR, 2);
	 while ( Wire.available() ) 
	 {
		bh_buff[i] = Wire.read();
		i++;
	 }
	 Wire.endTransmission();
	 if ( 2 == i )
	 {
		val=((bh_buff[0]<<8) | bh_buff[1])/1.2;
	 }
	 return val;
}

///////////////////////////////////////////////////////////////////////////////
// Main
CYaoji 	yaoji;

void setup()
{
	yaoji.init();
}

void loop()
{
	yaoji.updateSensors();					// Update all sensors
	yaoji.commWithClient();					// Communication with client
	yaoji.interactFromEnv();
	yaoji.decisionMake();
//	yaoji.takeAction();
	yaoji.refreshRGB();
//	yaoji.selfCheck();
}

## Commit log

2013-06-23 Add reference data and schematic file
2016-05-04 16/05/04 - Added Photos and Arduino FastSPI library.
